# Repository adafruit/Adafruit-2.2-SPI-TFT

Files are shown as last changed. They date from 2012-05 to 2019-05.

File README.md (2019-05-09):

# Adafruit 2.2" 18-bit color TFT LCD display with microSD card breakout 

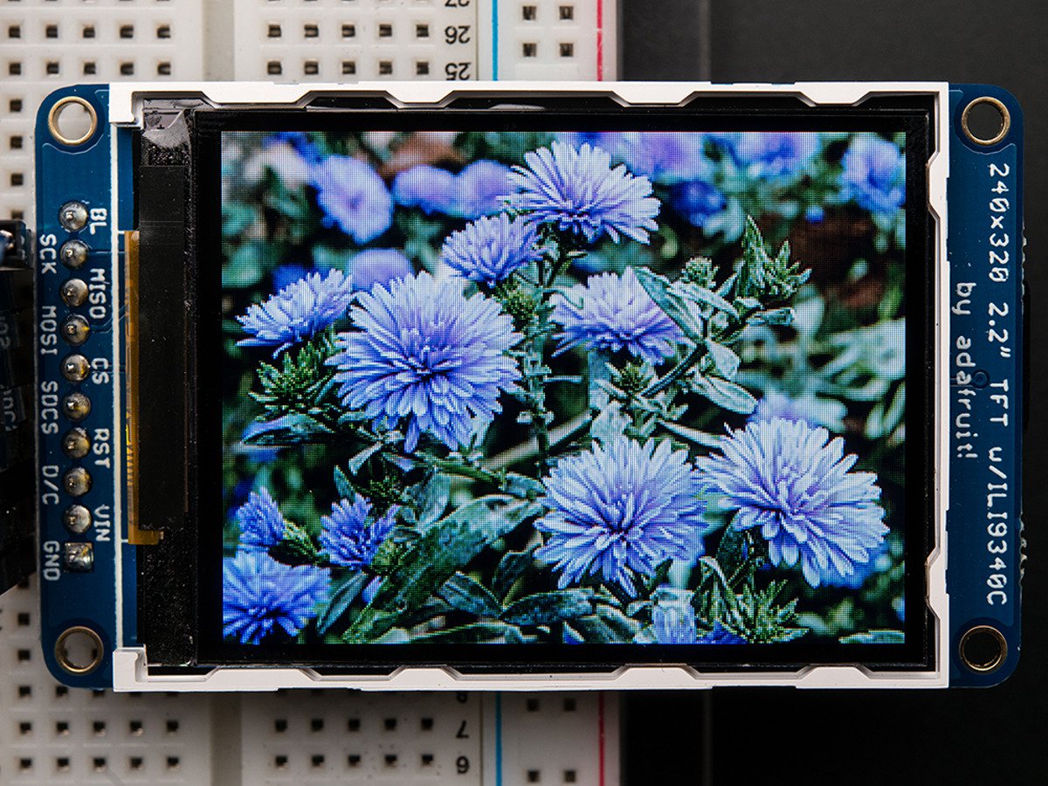
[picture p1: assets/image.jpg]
<a href="http://www.adafruit.com/products/1480"><br/>Click here to purchase one from the Adafruit shop</a>

These are the Eagle CAD files for the Adafruit 2.2" 18-bit color TFT LCD display with microSD card breakout:
  * https://www.adafruit.com/products/797 (older 220x178 HX8340BN version)
  * http://www.adafruit.com/products/1480 (newer 320x240 ILI9340 version)

This lovely little display breakout is the best way to add a small, colorful and bright display to any project. Since the display uses 3-wire SPI to communicate and has its own pixel-addressable frame buffer, it can be used with every kind of microcontroller. Even a very small one with low memory and few pins available! 

The 2.2" display has 220x176 color pixels. Unlike the low cost "Nokia 6110" and similar LCD displays, which are CSTN type and thus have poor color and slow refresh, this display is a true TFT! The TFT driver (HX8340) can display full 18-bit color (262,144 shades!). And the LCD will always come with the same driver chip so there's no worries that your code will not work from one to the other. 

The breakout has the TFT display soldered on (it uses a delicate flex-circuit connector) as well as a ultra-low-dropout 3.3V regulator and a 3/5V level shifter so you can use it with 3.3V or 5V power and logic. We also had a little space so we placed a microSD card holder so you can easily load full color bitmaps from a FAT16/FAT32 formatted microSD card.

## License

Adafruit invests time and resources providing this open source design, 
please support Adafruit and open-source hardware by purchasing 
products from Adafruit!

Designed by Limor Fried/Ladyada for Adafruit Industries.
Creative Commons Attribution/Share-Alike, all text above must be included in any redistribution
All text above must be included in any redistribution

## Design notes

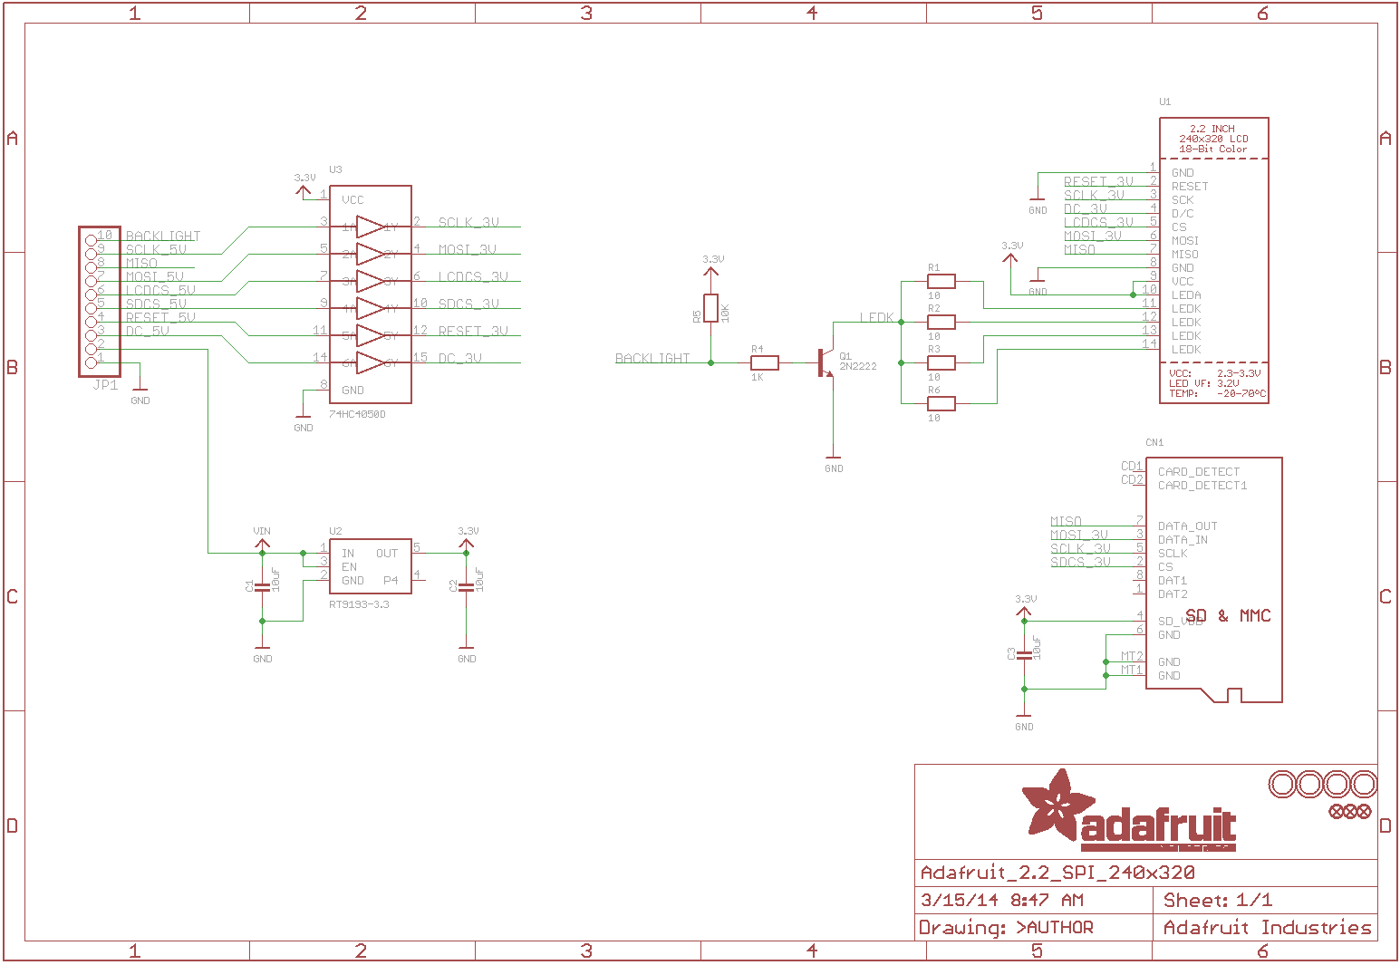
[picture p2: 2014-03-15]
Adafruit_2.2_SPI_240x320.png

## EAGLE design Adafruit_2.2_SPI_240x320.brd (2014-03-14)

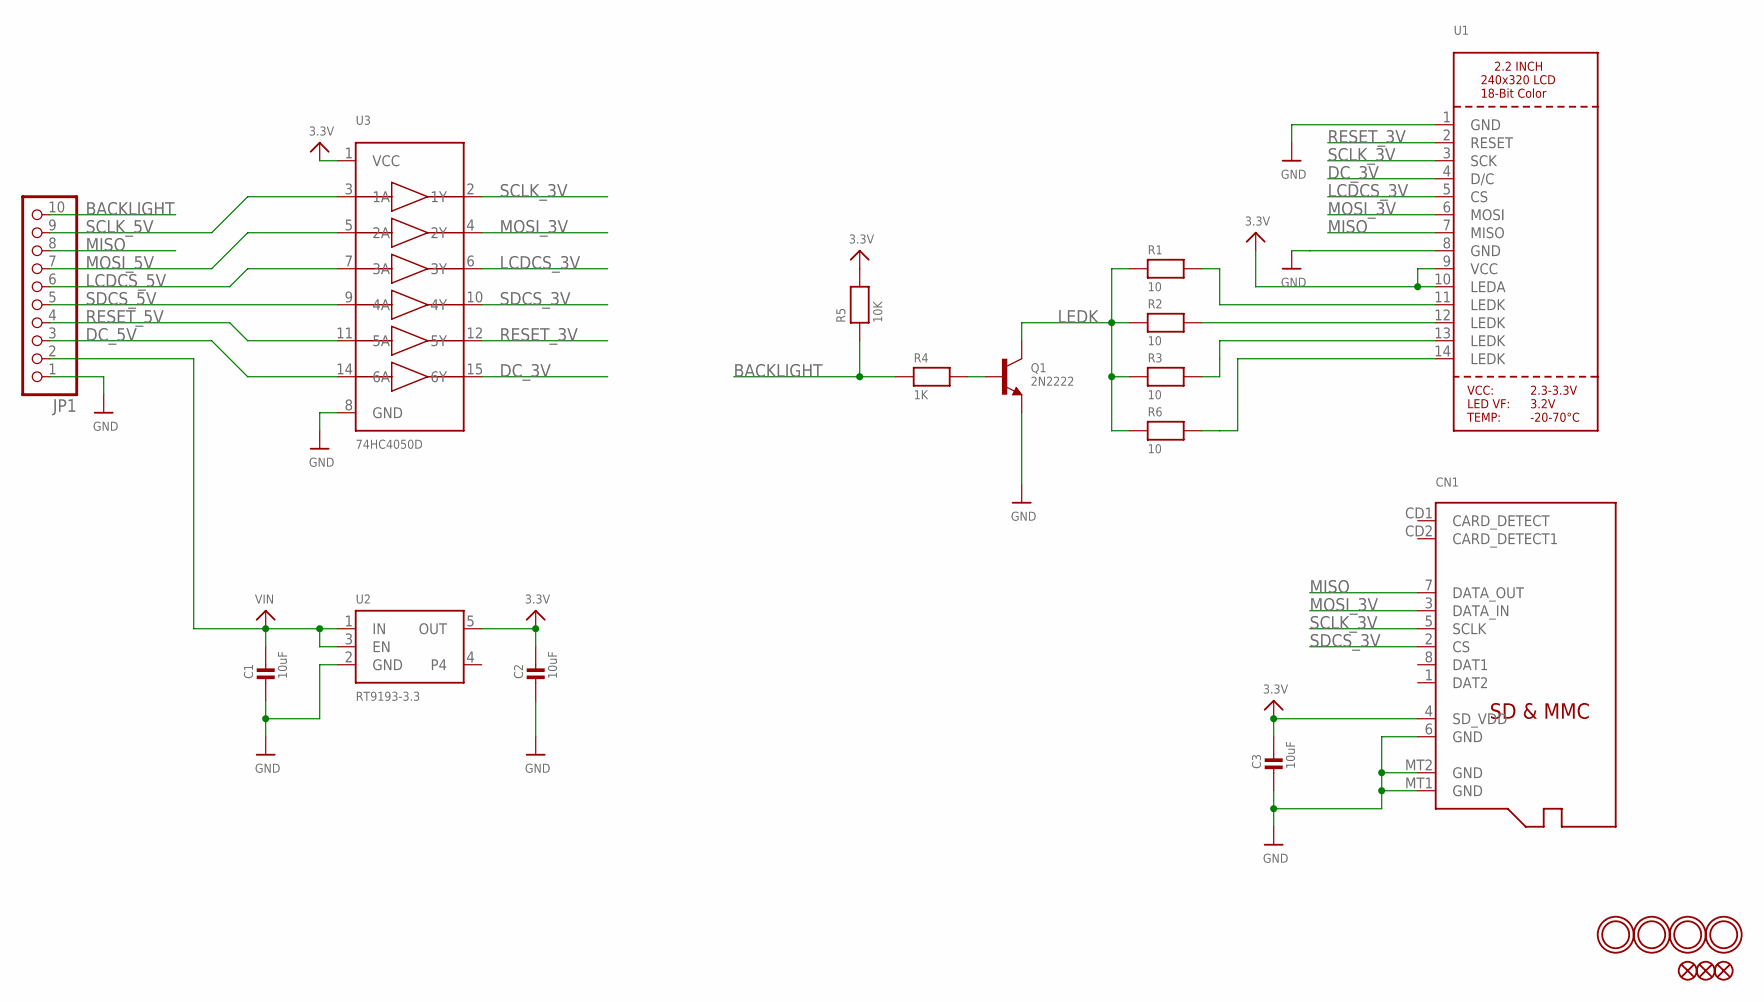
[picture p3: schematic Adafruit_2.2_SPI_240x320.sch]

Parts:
C1, C2, C3: 10uF; _0805MP
CN1: MICROSD
FID1, FID2, FID3: FIDUCIAL""; FIDUCIAL_1MM
JP1: HEADER-1X1070MIL; 1X10_ROUND70
Q1: 2N2222; SOT23-WIDE
R1, R2, R3, R6: 10; _0805MP
R4: 1K; _0805MP
R5: 10K; _0805MP
U1: DISP_LCD_TM022HDH26; TM022HDH26_2.2IN_LCD
U2: RT9193-3.3; SOT23-5
U3: 74HC4050D; SOIC16
U$2, U$3, U$4, U$5: MOUNTINGHOLE2.5; MOUNTINGHOLE_2.5_PLATED

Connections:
3.3V: C2.1, C3.1, CN1.4 (SD_VDD), R5.2, U1.9 (VCC), U1.10 (LEDA), U2.5 (OUT), U3.1 (VCC)
BACKLIGHT: JP1.10, R4.1, R5.1
DC_3V: U1.4 (D/C), U3.15 (6Y)
DC_5V: JP1.3, U3.14 (6A)
GND: C1.2, C2.2, C3.2, CN1.6 (GND), CN1.MT1 (GND), CN1.MT2 (GND), JP1.1, Q1.2 (E), U1.1 (GND), U1.8 (GND), U2.2 (GND), U3.8 (GND)
LCDCS_3V: U1.5 (CS), U3.6 (3Y)
LCDCS_5V: JP1.6, U3.7 (3A)
LEDK: Q1.3 (C), R1.1, R2.1, R3.1, R6.1
MISO: CN1.7 (DATA_OUT), JP1.8, U1.7 (MISO)
MOSI_3V: CN1.3 (DATA_IN), U1.6 (MOSI), U3.4 (2Y)
MOSI_5V: JP1.7, U3.5 (2A)
unnamed: R1.2, U1.11 (LEDK)
unnamed: R2.2, U1.12 (LEDK)
unnamed: R3.2, U1.13 (LEDK)
unnamed: Q1.1 (B), R4.2
unnamed: R6.2, U1.14 (LEDK)
RESET_3V: U1.2 (RESET), U3.12 (5Y)
RESET_5V: JP1.4, U3.11 (5A)
SCLK_3V: CN1.5 (SCLK), U1.3 (SCK), U3.2 (1Y)
SCLK_5V: JP1.9, U3.3 (1A)
SDCS_3V: CN1.2 (CS), U3.10 (4Y)
SDCS_5V: JP1.5, U3.9 (4A)
VIN: C1.1, JP1.2, U2.1 (IN), U2.3 (EN)

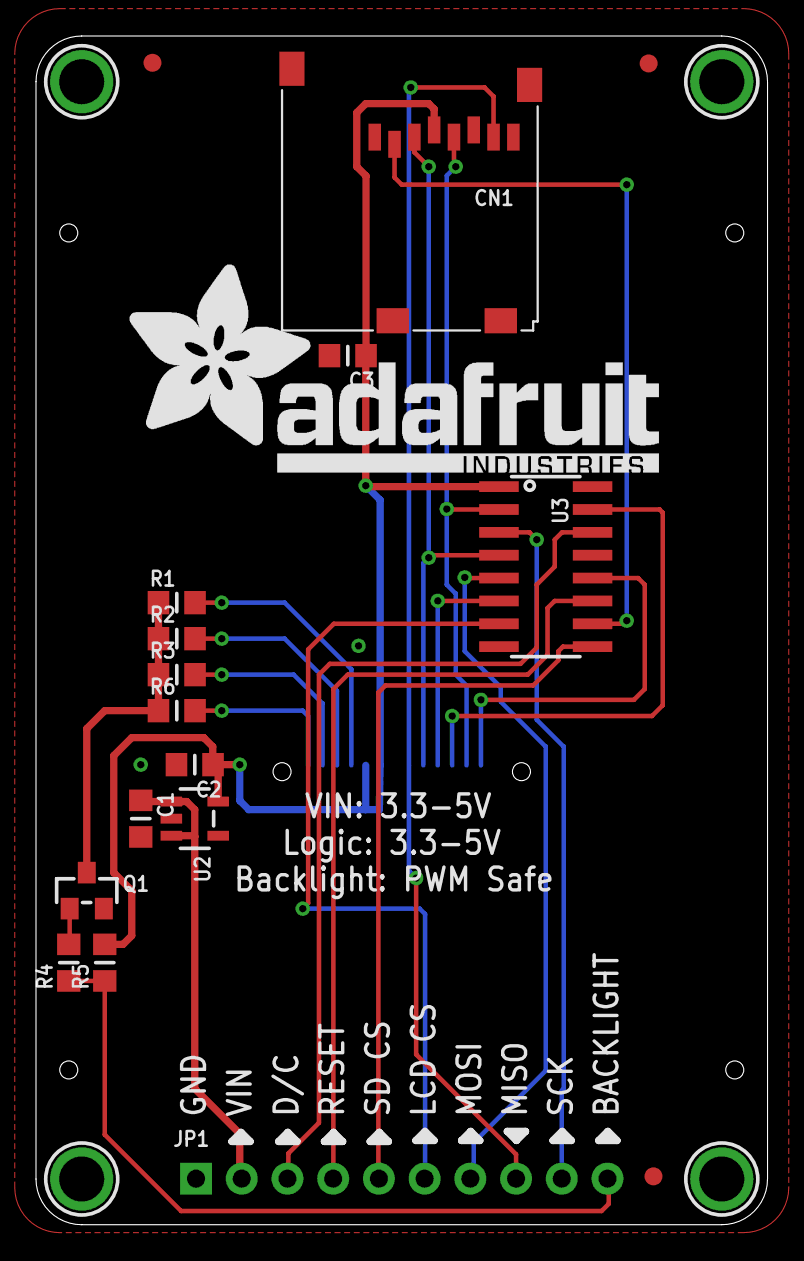
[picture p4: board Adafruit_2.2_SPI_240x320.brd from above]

Board: 2 copper layers, 40.6 x 66.0 mm, 23 parts (1 on the bottom side), 23 nets.

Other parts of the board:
U$20: ADAFRUIT_TEXT_30MM

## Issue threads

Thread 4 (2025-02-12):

Updated schematics with EYESPI connector

arampante, 2025-02-12:
The design files currently present do not correspond to the newest version of the display that has the EYESPI connector. It would be quite useful to have the latest in here. Thanks

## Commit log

2012-05-04 Adafruit 2.2" 18-bit color TFT LCD display with microSD card breakout
    Adafruit 2.2" 18-bit color TFT LCD display with microSD card breakout
    [Adafruit-2.2-SPI-TFT-v0.2.brd, Adafruit-2.2-SPI-TFT-v0.2.sch]
2014-03-14 Added the new ILI9340 version!
    [Adafruit_2.2_SPI_240x320.brd, Adafruit_2.2_SPI_240x320.sch]
2014-03-15 Added PNG of ILI9340 schematic
    PNG of ILI9340 schematic
